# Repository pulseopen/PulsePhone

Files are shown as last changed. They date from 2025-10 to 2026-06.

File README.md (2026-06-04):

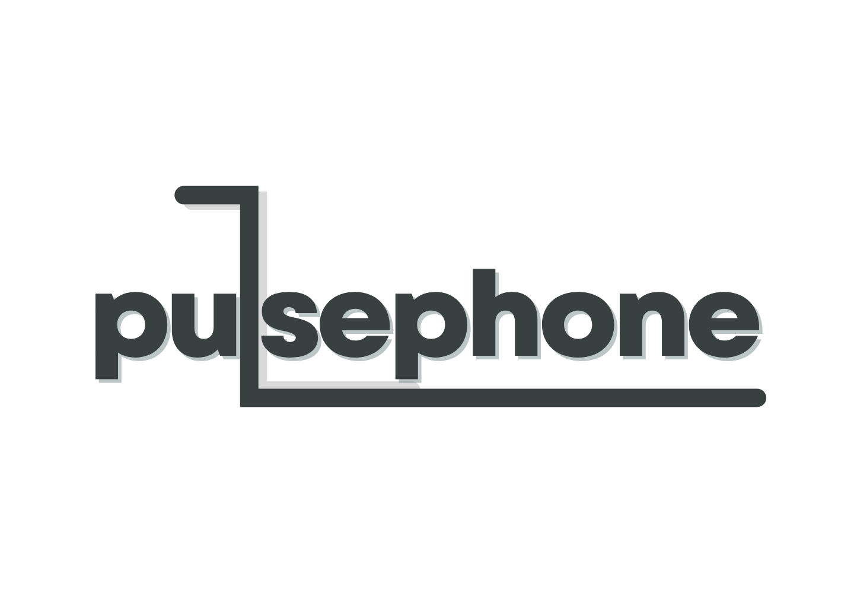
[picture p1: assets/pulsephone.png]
Pulsephonelogo


# PulsePhone — Pulse Modular Phone (MCM-iMX93 SoM)

> A modular, open-source smartphone built for repairability, upgradability, and hardware freedom.

Built around the **MCM-iMX93 System-on-Module**, PulsePhone uses **Hirose DF40** board-to-board connectors across all subsystems — keeping modules isolated, swappable, and independently developable.

---

## System Architecture

The **Main Board** is the hub of the system, hosting the MCM-iMX93 SoM, an onboard DAC, and all signal routing. Every peripheral connects to it via DF40 connectors.

| Module | Interface | Role |
|---|---|---|
| Main Board | DF40 (host) | MCM-iMX93 SoM, DAC, signal routing |
| Display Module  | MIPI/LVDS + Touch | Adapter for wide MIPI-DSI display compatability. |
| Camera Module  | MIPI CSI-2 | Adapter for wide MIPI-CSI camera compatability. |
| Audio Module | Analog | Amp, speaker, headphone, mic |

Full connector pinout in [MBI-Lite Specification](MBI-LITE.md).

---

## Project Goals

- One connector standard (DF40) across every module
- Linux (Debian + Phosh), Android, and Ubuntu Touch compatible
- Fully open: KiCad source + mechanical files under GNU GPL-V3.0

---

## Development Notes

### Main Board
> First prototype!
> Revamping design.
> PCB Design in final polishing and bug fix stages!

### Wi-Fi / Bluetooth (Former Module)
> Deffered to embedded inclusion on main board.

### Display Module
> PCB Design DONE!
> This module acts like an adapter, so PulsePhone can have a wide range of MIPI-DSI displays to be compatible with.

### Camera Module
> Design TBD

### Audio Module
> Design Started

### Mod Extension
> Planned inclusion. This extension will include an additional DF40 on the main board for community mods to the phone, like additional features.

---

## Current Project Status

- Almost ready to boot something.
- Working on wrapping up design for main board.

---

## Documentation

- Check out the [Wiki](https://github.com/pulseopen/PulsePhone/wiki)
- [MBI-Lite Module Connector Specification](MBI-LITE.md)
- [Contributing](CONTRIBUTING.md)
- [License](LICENSE)

---

## License

Hardware released under **GNU GPL-V3.0**.

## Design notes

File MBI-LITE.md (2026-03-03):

# MBI-Lite Specification — Modular Board Interconnect

MBI-Lite is the connector standard for PulsePhone's general-purpose DF-40 modules. Two blocks: Power and a flexible Custom block. Display and Camera have their own dedicated pinouts.

> **Dev Note:** DF-40 connectors are 34-pin instead of 30-pin — better mechanical stability, and honestly, 30-pin options were just hard to find.

---

## Pin Map

### Power (Pins 1–4)

| Pin | Name | Description |
|-----|---|---|
| 1 | 3V3  | Regulated 3.3V rail |
| 2 | 5V | Boosted 5V rail |
| 3 | BAT  | Raw battery voltage (3.7–4.2V) |
| 4 | GND  | Ground reference |

Don't back-feed any rail. BAT is raw battery voltage — treat it accordingly.

---

### Custom Block (Pins 5–22)

18 pins, fully open. Assign them however your module needs — GPIO, UART, SPI, I²S, USB, ADC, PWM, whatever fits. No mandated mapping.

Constraints:
- All pins operate at **3.3V (or lower) logic**
- All pins default to **high-impedance** until configured
- Any differential pair must be routed with impedance control, Include GND pins between EVERY pair of differentials.
- Anything externally accessible needs handheld-grade ESD protection

**Documentation is required.** For every pin you use, you must provide a clear description of its assignment, the reasoning behind it, any relevant electrical characteristics (pull-ups, drive strength, impedance, etc.), and how it interacts with the rest of the module. Undocumented pin usage is not up to standard with our requirements.

---

### Reserved (Pins 23–34)

Reserved for future GPIOs, system features, or optional high-speed lanes. Leave unassigned unless stated in a future revision.

---

## Electrical Rules

A few interface-specific things to keep in mind:

- **UART** — 22–100Ω series resistors recommended
- **SPI** — document clock polarity/phase in your module's profile
- **I²S** — declare whether your module is clock master or slave
- **ADC** — specify input impedance; add overvoltage protection
- **PWM** — logic-level only, add an external driver for any real load

---

## Backwards Compatibility

Modules that use pins beyond the basics will still work on boards that only implement a subset — they just won't use those features. Each module should document which pins it uses.

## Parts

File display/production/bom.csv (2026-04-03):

Designator | Footprint | Quantity | Value | LCSC Part #
C1, C2, C3, C4, C5, C6, C7, C8, C9 | 1206 | 9 | 20uF
J1 | FPC-29-P0.5 | 1 | THD THD0515-29CL-SN
J2 | FPC_7 | 1 | FPC LOGIC
J4 | Hirose_DF40C-34DS-0.4V_2x17_P0.4mm | 1 | DF40
R1 | 1206 | 1 | 100 OHM

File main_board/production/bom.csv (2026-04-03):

Designator | Footprint | Quantity | Value | LCSC Part #
3.3V1, 5V1, CLK-N1, CLK-P1, D0-N1, D0-P1, D1-N1, D1-P1, D2-N1, D2-P1, D3-N1, D3-P1, GND1, I2C3-SCL1, I2C3-SDA1, VBAT1 | TestPoint_Pad_D1.0mm | 16 | TestPoint
AUD-L1, AUD-R1 | TestPoint_Pad_1.0x1.0mm | 2 | TestPoint
BT1 | PinHeader_1x02_P2.54mm_Horizontal | 1 | Battery
C1, C10, C11, C14, C15, C16, C17, C18, C19, C20, C21, C22, C23, C24, C25, C26, C27, C28, C29, C30, C31, C32, C35, C36, C37, C7, C8, C9 | 0805 | 28 | 22uF
C12, C13, C2, C3, C33, C34, C6 | 0603 | 7 | 10uF
C4, C5 | 0603 | 2 | 2.2uF
C43 | 0603 | 1 | 100nF
D1, D4 | D_SMA | 2 | D_Schottky
D5 | 0805 | 1 | LED
J1 | USB_C_Receptacle_HRO_TYPE-C-31-M-12 | 1 | USB_C_Receptacle_USB2.0_14P
J2 | PinHeader_1x05_P2.54mm_Horizontal | 1 | Conn_01x05
J3, J4, J5 | HIROSE_DF40C-34DS-0.4V_58_ | 3 | Conn_2Rows-35Pins_MountingPin
J7 | microSD_HC_Hirose_DM3AT-SF-PEJM5 | 1 | Micro_SD_Card_Det1
L1 | L_KOHERelec_MDA7030 | 1 | 47uh
L2 | L_Wurth_WE-LQSH-4020 | 1 | 1uH
L3 | L_Wurth_WE-LQSH-4020 | 1 | 1.5uH
MCM93_MOD1 | LGA-140-080-30x30-iMX93 | 1 | MCM93_MOD
ON/OFF1 | SSSS810701 | 1 | SW_Push
R1 | 0603 | 1 | 1Mega Ohm
R10 | 0805 | 1 | 1 MΩ
R11 | 0805 | 1 | 51 kΩ
R2, R3 | 0805 | 2 | 5.1 kΩ
R4 | 0805 | 1 | 1.2 kΩ
R5, R6 | 0805 | 2 | 10 kΩ
R7 | 0805 | 1 | 1.1 MΩ
R8 | 0805 | 1 | 1kΩ
R9 | 0805 | 1 | 174 kΩ
RESET1 | SW_Push_1P1T-SH_NO_CK_KMR2xxG | 1 | SW_Push
U1 | SOIC-8_3.9x4.9mm_P1.27mm | 1 | XL1509-3.3
U2 | SOP65P640X120-20N | 1 | PCM5102APWR
U3 | VREG_MIC2877-AYFT-TR | 1 | ~
U4 | IC_TPS63020DSJR | 1 | TPS63020DSJR/3.7V Reg
U5 | SOIC-8-1EP_3.9x4.9mm_P1.27mm_EP2.41x3.3mm_ThermalVias | 1 | TP4056-42-ESOP8

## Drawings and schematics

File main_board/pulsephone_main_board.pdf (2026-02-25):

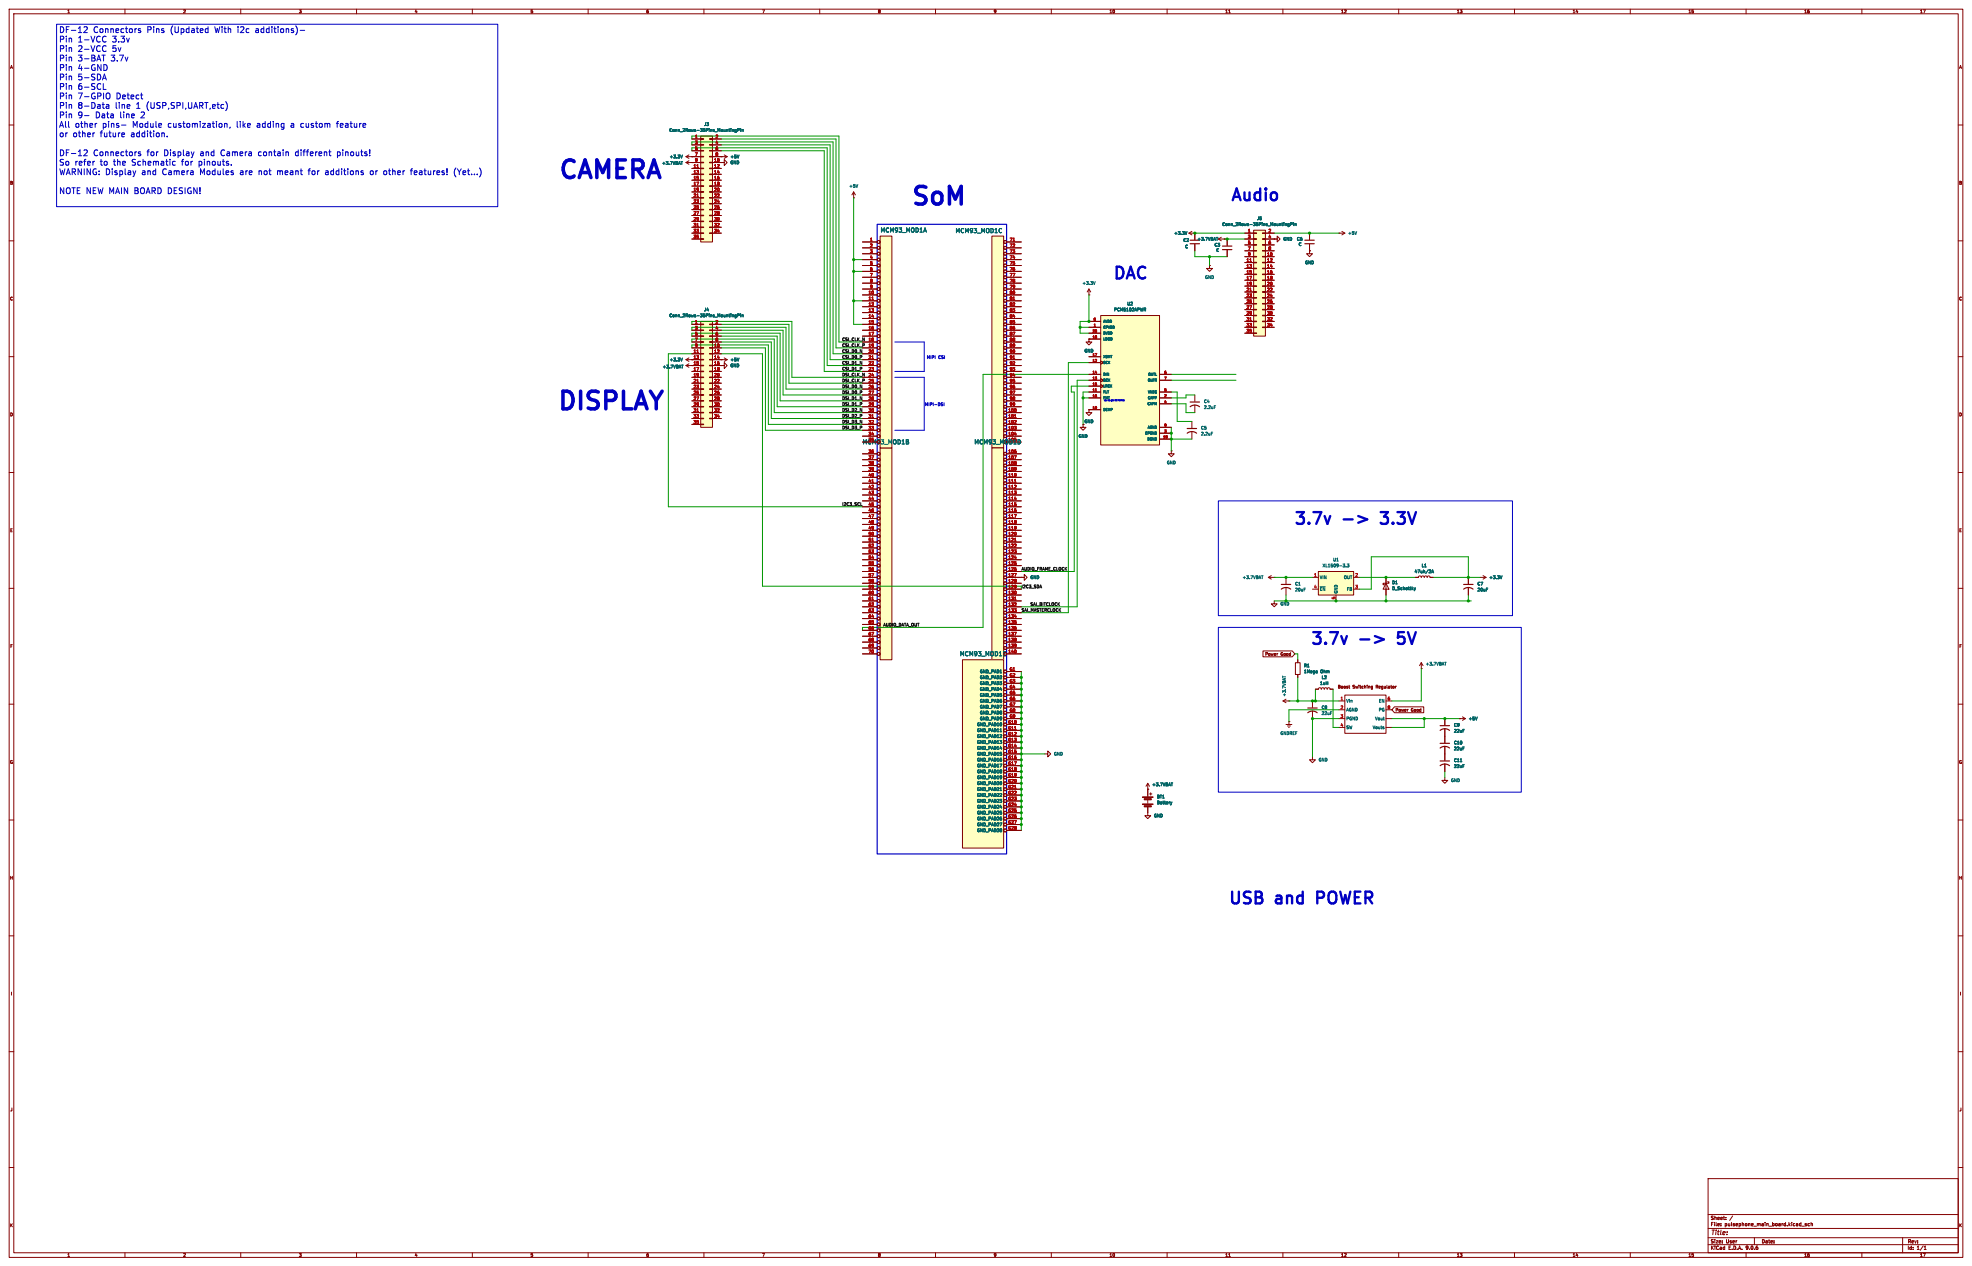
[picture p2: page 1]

Low to get I2C Format CAMERA

Power Good

Id: 1/1 Title: File: pulsephone_main_board.kicad_sch Sheet: /

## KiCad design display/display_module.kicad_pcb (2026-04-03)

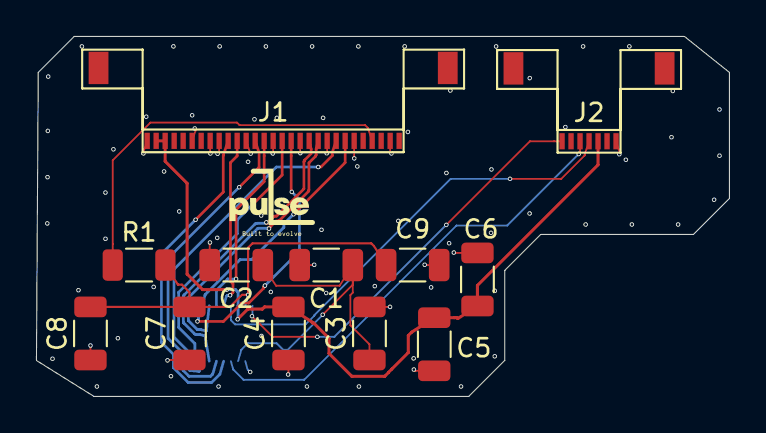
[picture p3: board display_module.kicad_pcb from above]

Board: 4 copper layers, 38.5 x 20.0 mm, 13 parts (1 on the bottom side), 18 nets.

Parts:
C1, C2, C3, C4, C5, C6, C7, C8, C9: 20uF; C_1206_3216Metric
J1: THD THD0515-29CL-SN; FPC-29-P0.5
J2: FPC LOGIC; FPC_7
J4: DF40; Hirose_DF40C-34DS-0.4V_2x17_P0.4mm
R1: 100 OHM; R_1206_3216Metric

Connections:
+3.3V: C4.2, C5.2, C6.2, J1.27, J1.28, J2.3, J4.13
+3.7VBAT: C7.2, C8.2, C9.2, J4.15, R1.2
+5V: C1.1, C2.1, C3.1, J4.14
DSI-0-N: J1.7, J4.3
DSI-0-P: J1.8, J4.4
DSI-1-N: J1.10, J4.5
DSI-1-P: J1.11, J4.6
DSI-2-N: J1.16, J4.7
DSI-2-P: J1.17, J4.8
DSI-3-N: J1.19, J4.9
DSI-3-P: J1.20, J4.10
DSI-CLK-N: J1.13, J4.1
DSI-CLK-P: J1.14, J4.2
GND: C1.2, C2.2, C3.2, C4.1, C5.1, C6.1, C7.1, C8.1, C9.1, J1.2, J1.6, J1.9, J1.12, J1.15, J1.18, J1.21, J1.22, J1.24, J1.29, J2.1, J4.16
I2C3-SCL: J2.4, J4.11
I2C3-SDA: J2.5, J4.12
unnamed: J1.4, R1.1
RST: J2.7, J4.17

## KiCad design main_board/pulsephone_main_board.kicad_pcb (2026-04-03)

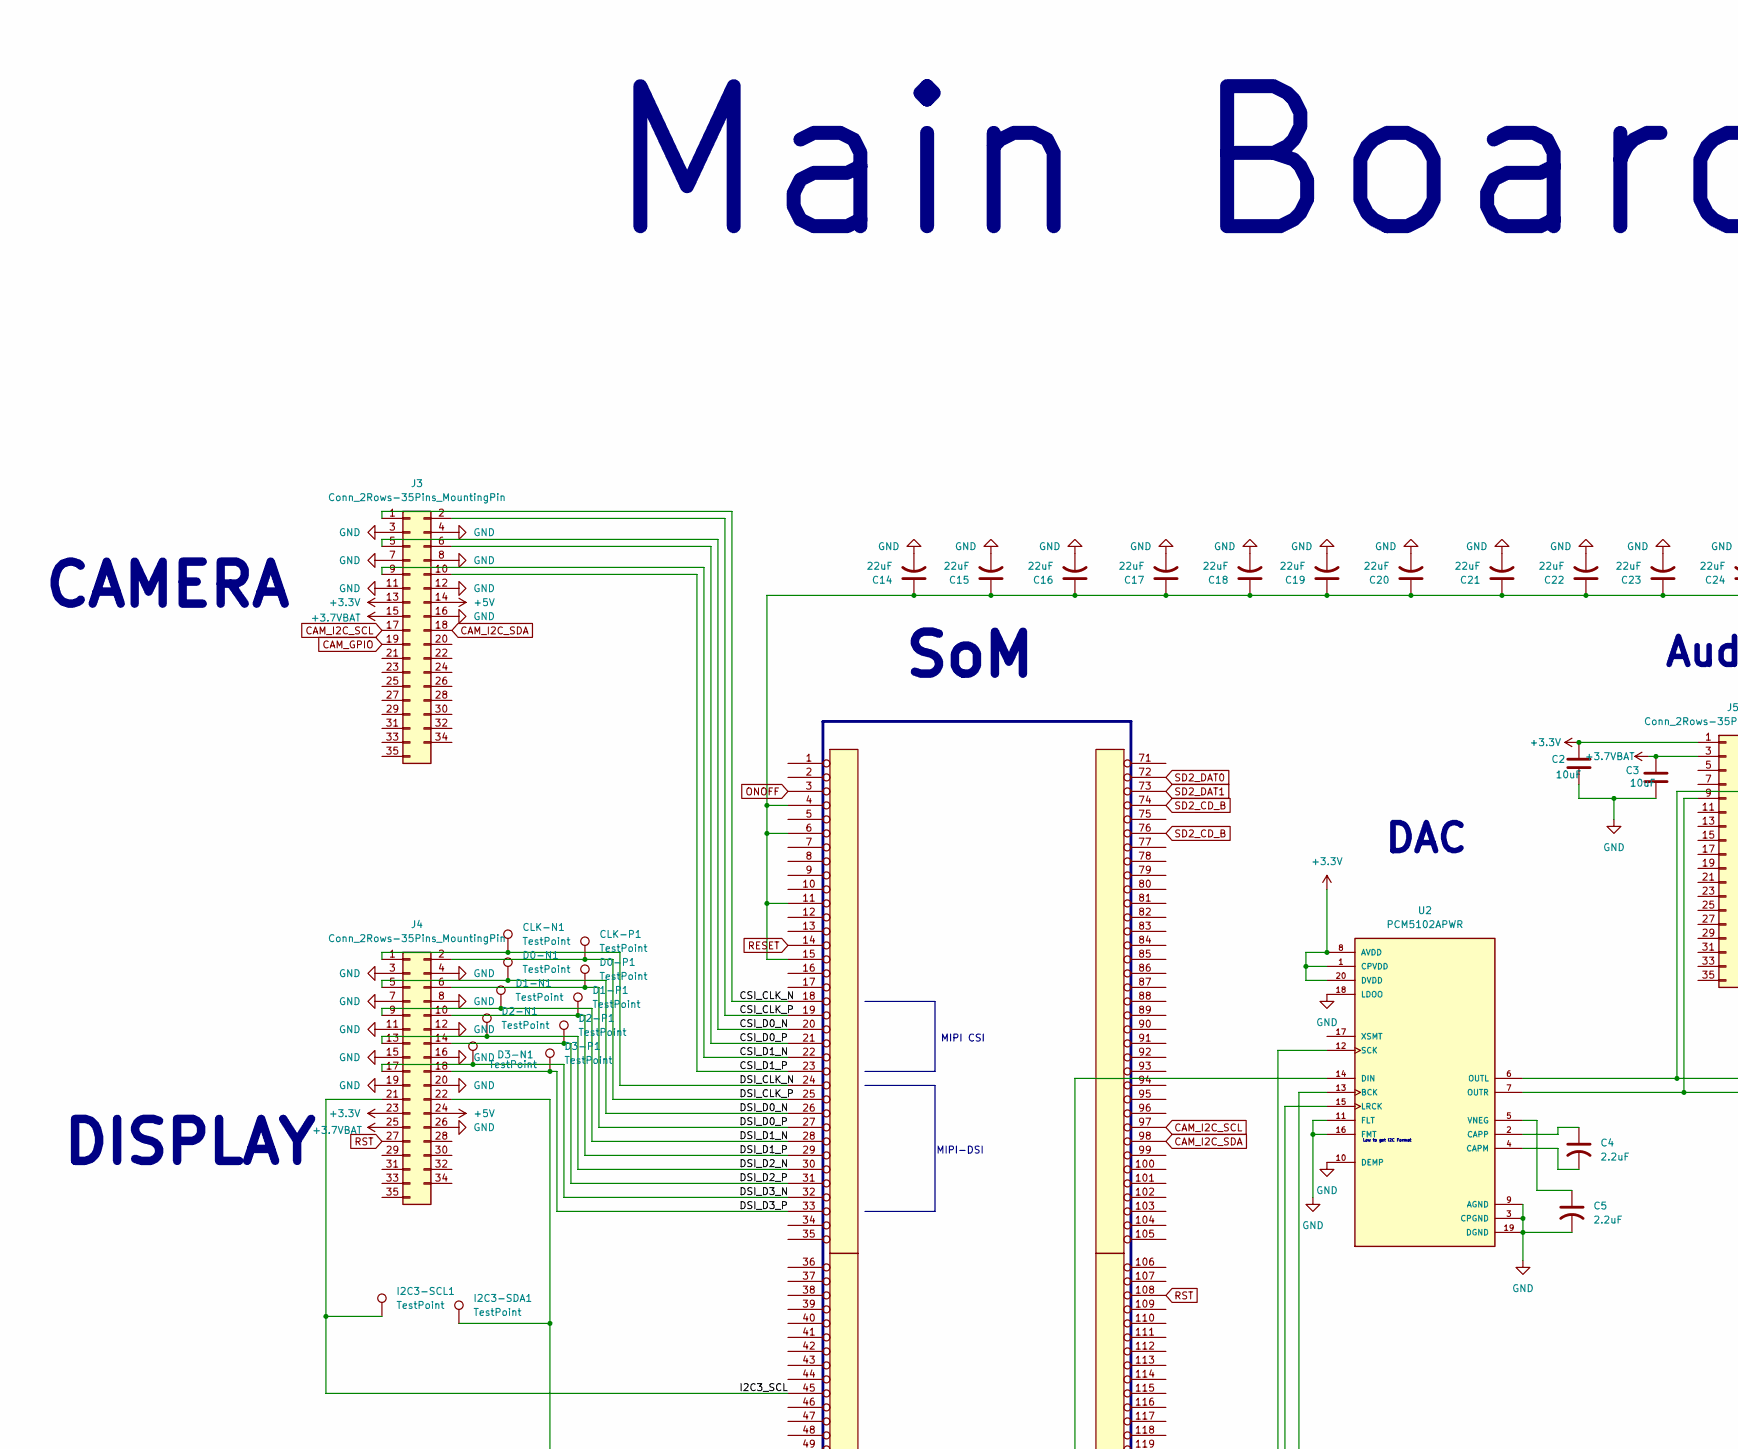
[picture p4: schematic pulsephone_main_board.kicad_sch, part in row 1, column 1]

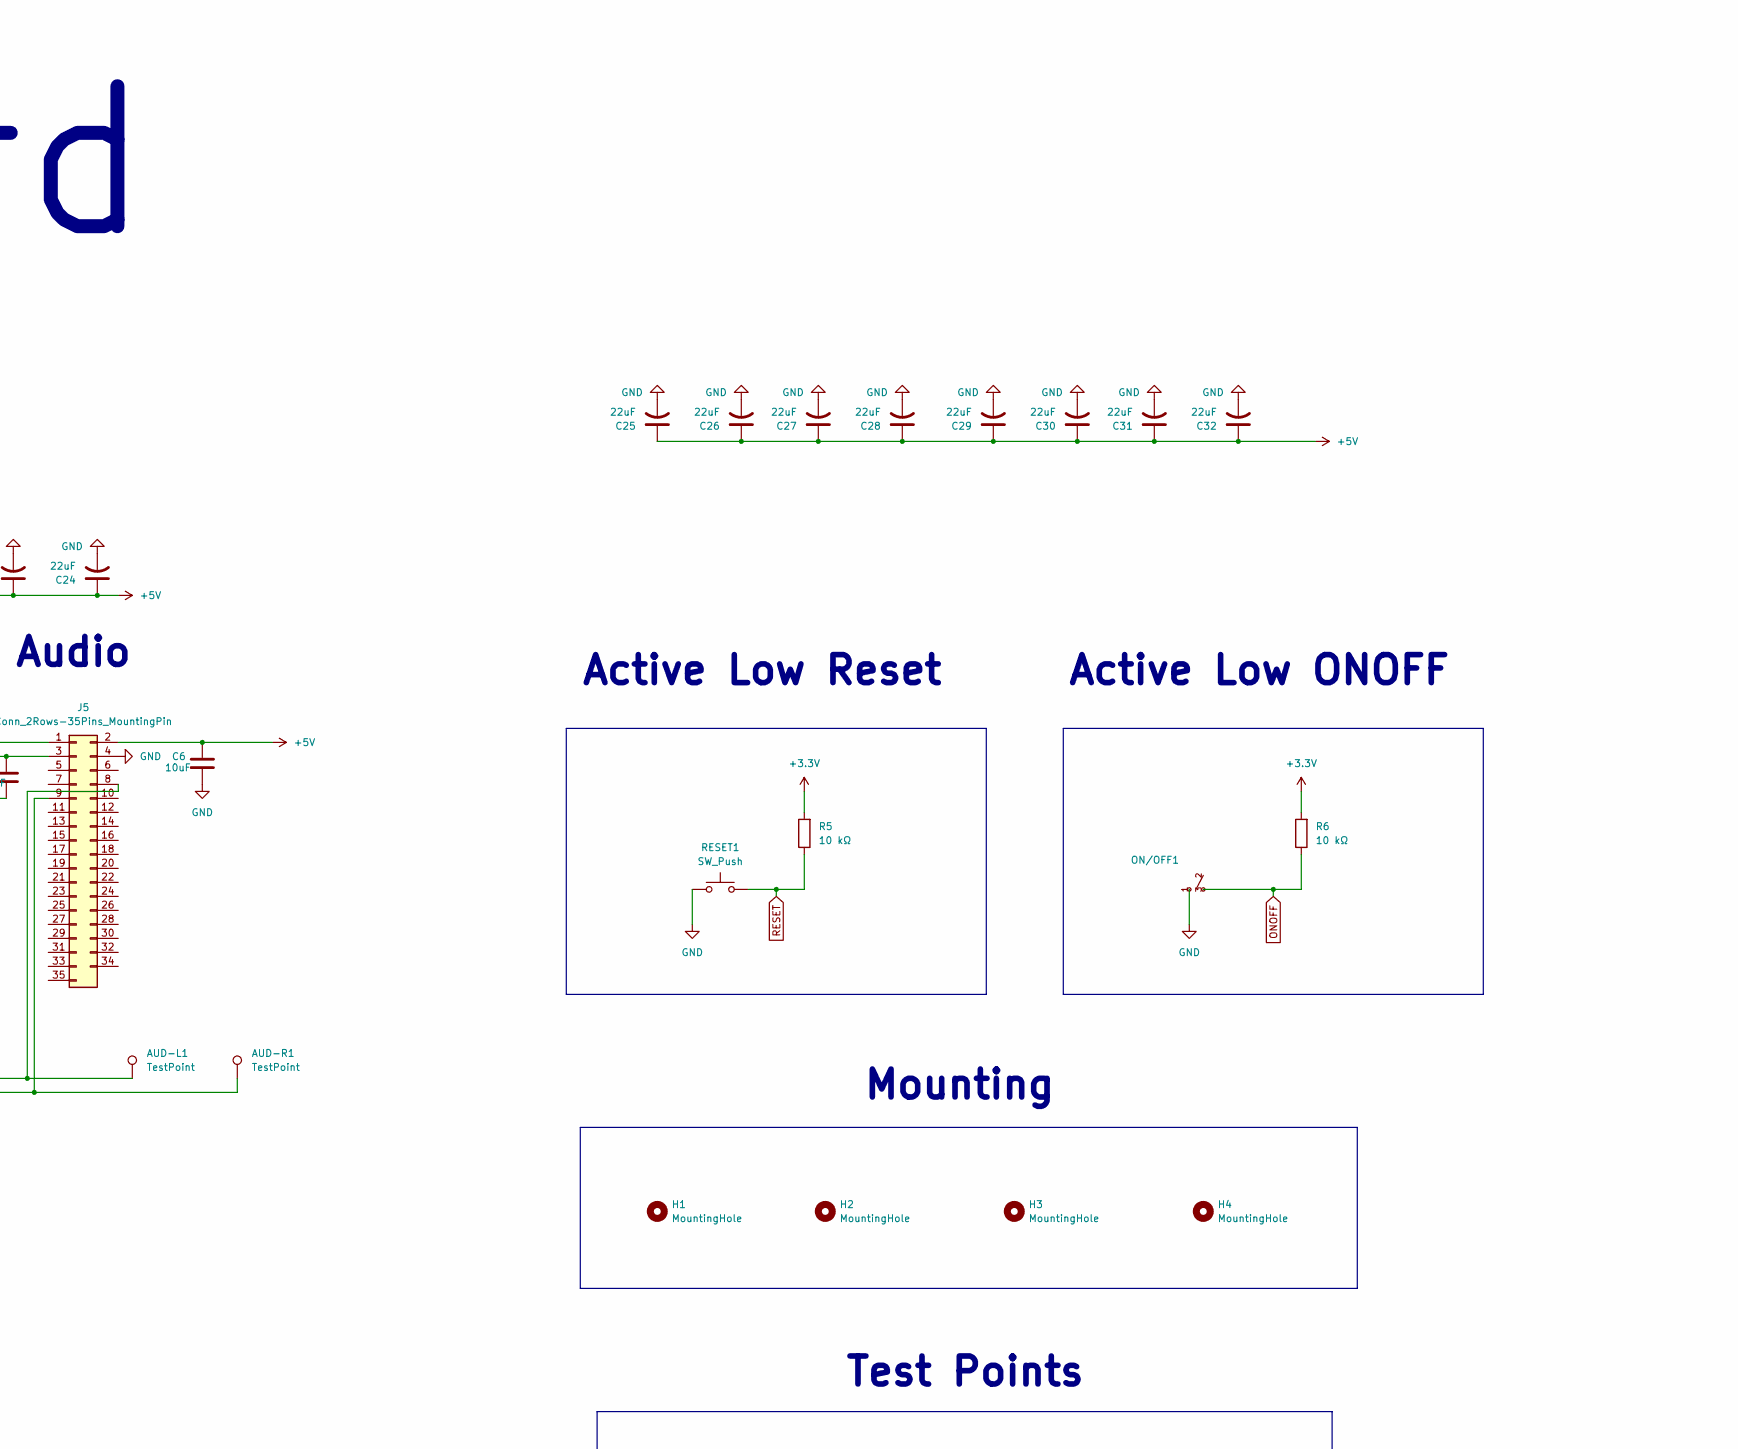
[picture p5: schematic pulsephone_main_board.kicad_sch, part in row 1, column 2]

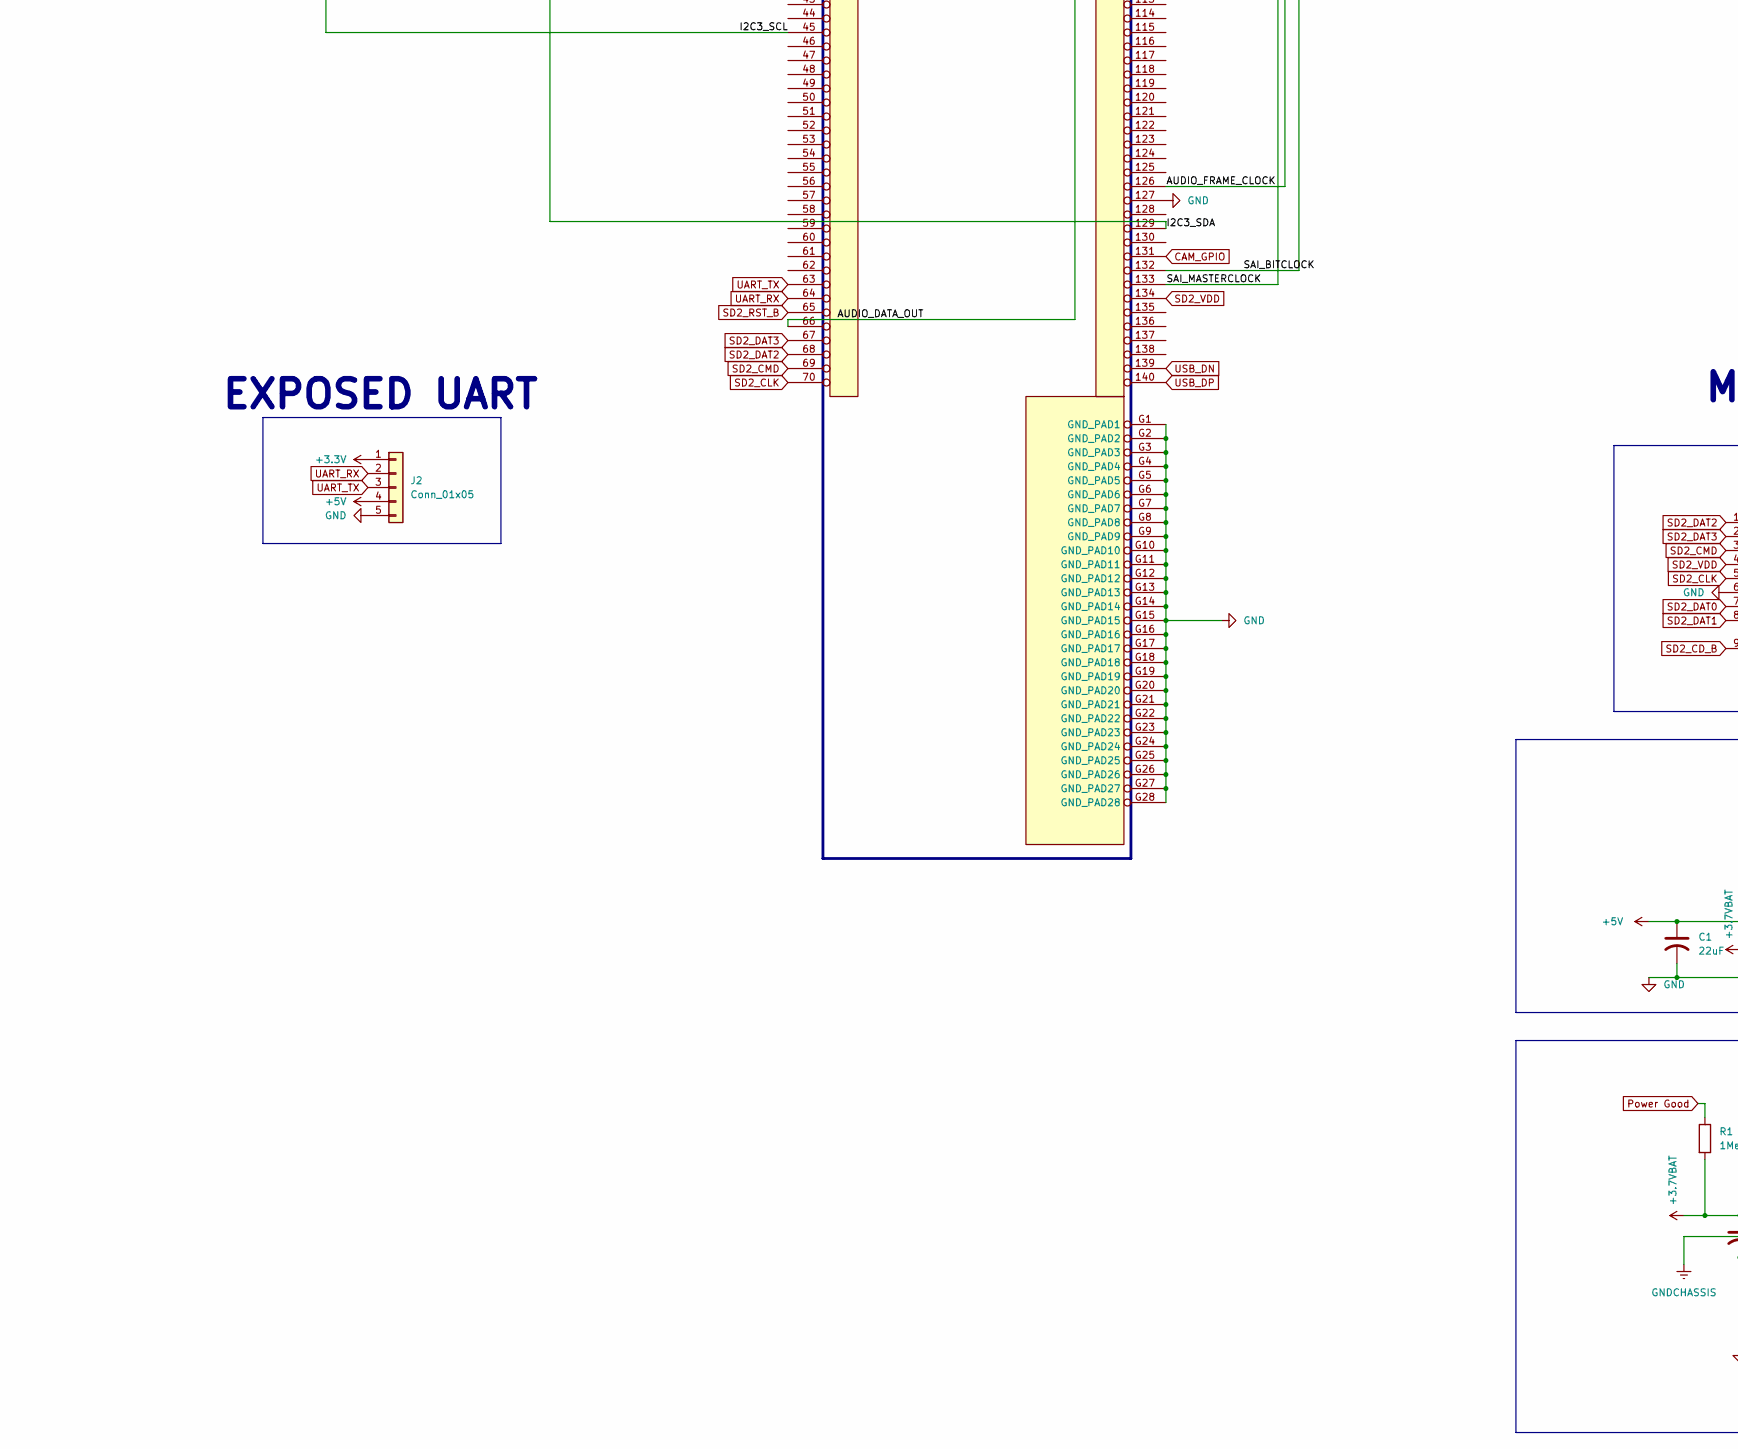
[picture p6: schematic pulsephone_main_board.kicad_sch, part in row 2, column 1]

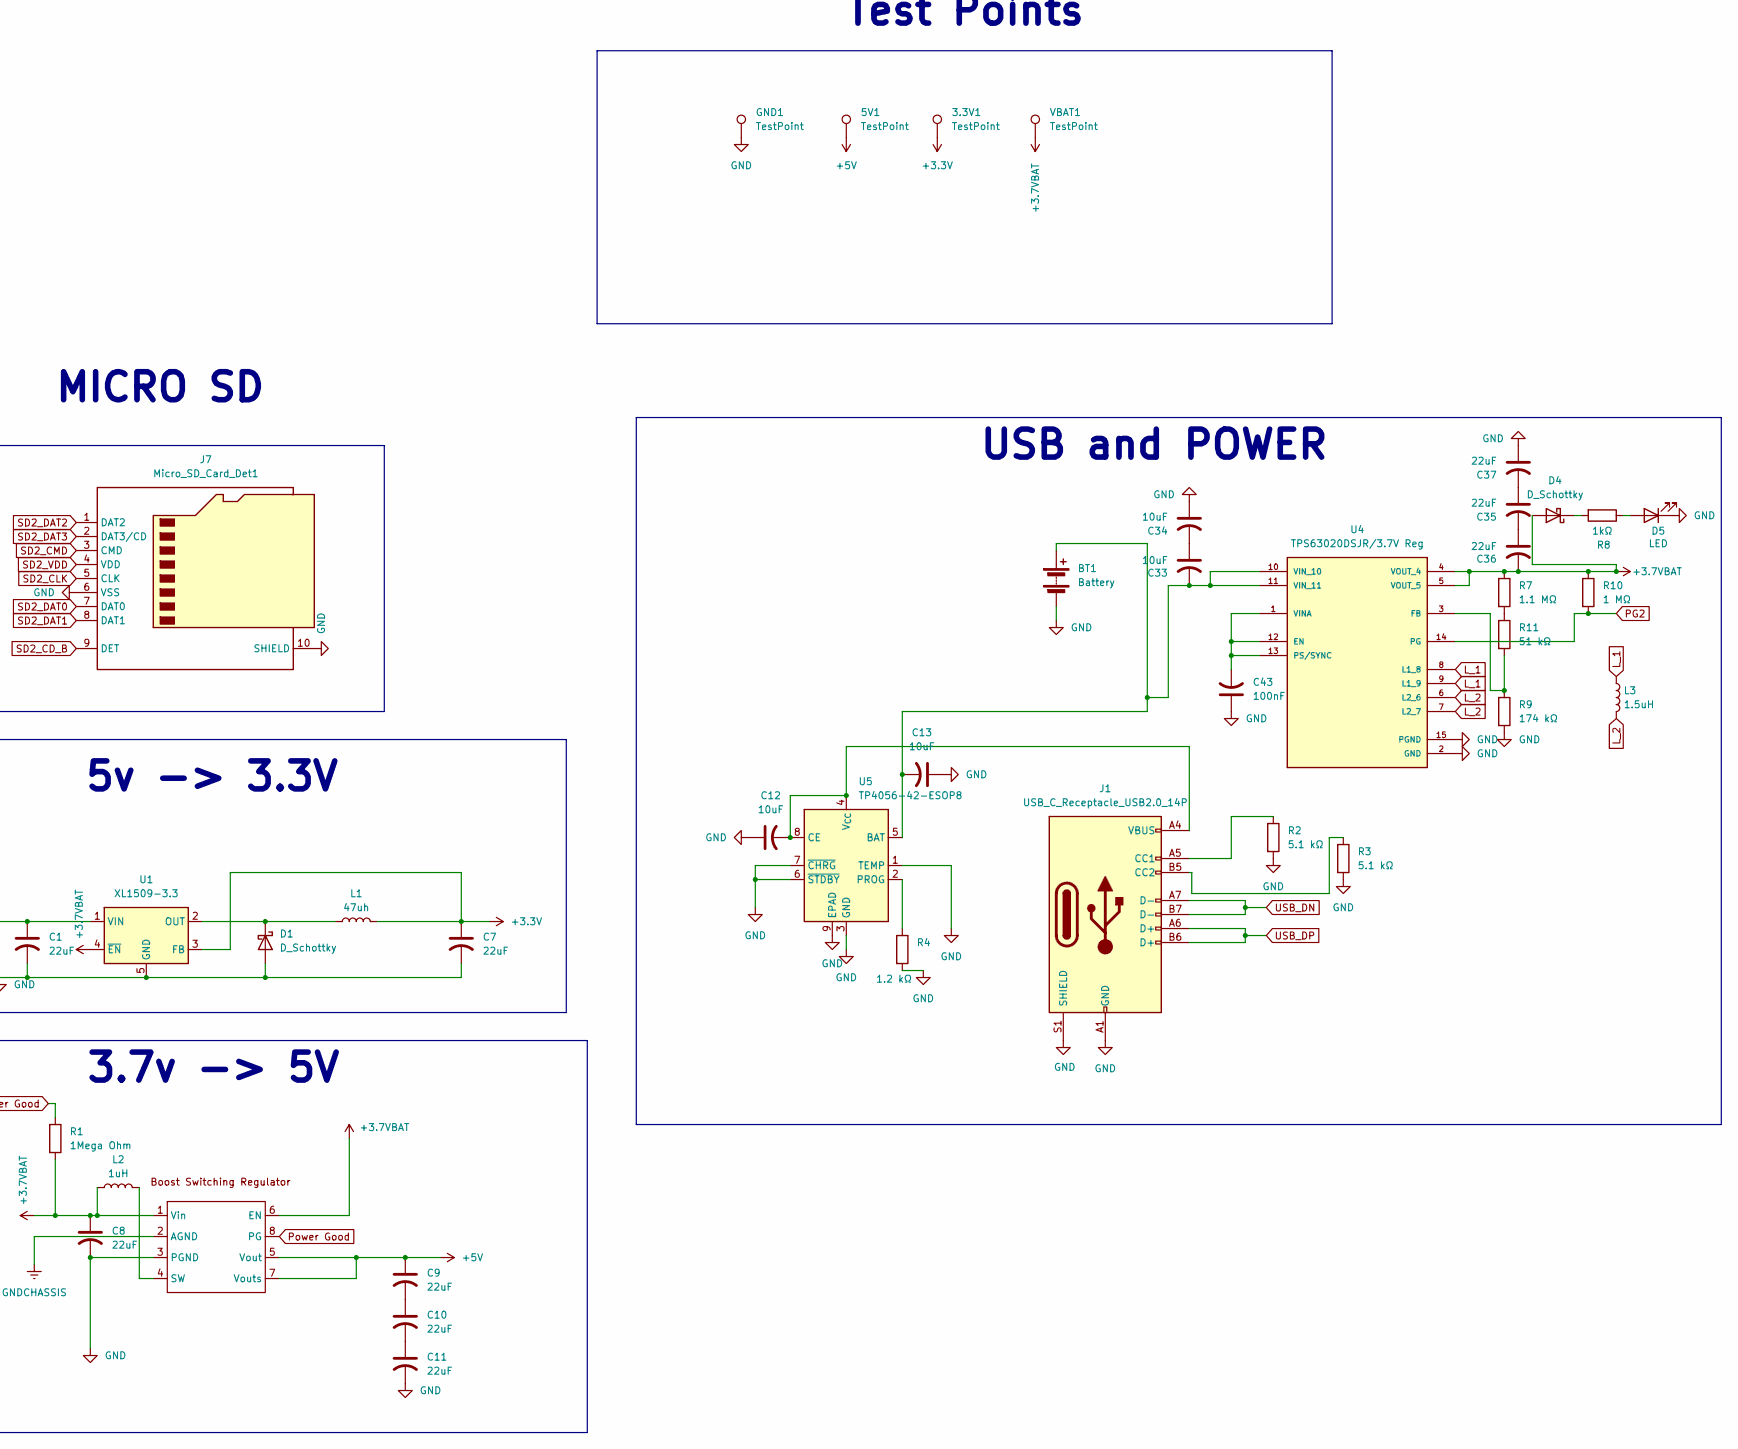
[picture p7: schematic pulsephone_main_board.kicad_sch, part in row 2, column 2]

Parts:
3.3V1, 5V1: TestPoint; TestPoint_Pad_D1.0mm
AUD-L1: TestPoint; TestPoint_Pad_1.0x1.0mm
AUD-R1: TestPoint; TestPoint_Pad_1.0x1.0mm
BT1: Battery; PinHeader_1x02_P2.54mm_Horizontal
C1, C7, C8, C9, C10, C11, C14, C15, C16, C17, C18, C19, C20, C21, C22, C23, C24, C25, C26, C27, C28, C29, C30, C31, C32, C35, C36, C37: 22uF; C_0805_2012Metric
C2, C3, C6, C12, C13, C33, C34: 10uF; C_0603_1608Metric
C4, C5: 2.2uF; C_0603_1608Metric
C43: 100nF; C_0603_1608Metric
CLK-N1: TestPoint; TestPoint_Pad_D1.0mm
CLK-P1: TestPoint; TestPoint_Pad_D1.0mm
D0-N1, D0-P1, D1-N1, D1-P1, D2-N1, D2-P1, D3-N1, D3-P1: TestPoint; TestPoint_Pad_D1.0mm
D1, D4: D_Schottky; D_SMA
D5: LED; LED_0805_2012Metric
GND1: TestPoint; TestPoint_Pad_D1.0mm
H1, H2, H3, H4: MountingHole; MountingHole_2.2mm_M2_DIN965_Pad
I2C3-SCL1, I2C3-SDA1: TestPoint; TestPoint_Pad_D1.0mm
J1: USB_C_Receptacle_USB2.0_14P; USB_C_Receptacle_HRO_TYPE-C-31-M-12
J2: Conn_01x05; PinHeader_1x05_P2.54mm_Horizontal
J3, J4, J5: Conn_2Rows-35Pins_MountingPin; HIROSE_DF40C-34DS-0.4V_58_
J7: Micro_SD_Card_Det1; microSD_HC_Hirose_DM3AT-SF-PEJM5
L1: 47uh; L_KOHERelec_MDA7030
L2: 1uH; L_Wurth_WE-LQSH-4020
L3: 1.5uH; L_Wurth_WE-LQSH-4020
MCM93_MOD1: MCM93_MOD; LGA-140-080-30x30-iMX93
ON/OFF1: SW_Push; SSSS810701
R1: 1Mega Ohm; R_0603_1608Metric_Pad0.98x0.95mm_HandSolder
R2, R3: 5.1 kΩ; R_0805_2012Metric
R4: 1.2 kΩ; R_0805_2012Metric
R5, R6: 10 kΩ; R_0805_2012Metric
R7: 1.1 MΩ; R_0805_2012Metric
R8: 1kΩ; R_0805_2012Metric
R9: 174 kΩ; R_0805_2012Metric
R10: 1 MΩ; R_0805_2012Metric
R11: 51 kΩ; R_0805_2012Metric
RESET1: SW_Push; SW_Push_1P1T-SH_NO_CK_KMR2xxG
U1: XL1509-3.3; SOIC-8_3.9x4.9mm_P1.27mm
U2: PCM5102APWR; SOP65P640X120-20N; PARTREV C
U3: VREG_MIC2877-AYFT-TR
U4: TPS63020DSJR/3.7V Reg; IC_TPS63020DSJR
U5: TP4056-42-ESOP8; SOIC-8-1EP_3.9x4.9mm_P1.27mm_EP2.41x3.3mm_ThermalVias
VBAT1: TestPoint; TestPoint_Pad_D1.0mm

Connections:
+3.3V: 3.3V1.1, C2.1, C7.1, J2.1, J3.13, J4.23, J5.1, L1.2, R5.2, R6.2, U1.3 (FB), U2.1 (CPVDD), U2.8 (AVDD), U2.20 (DVDD)
+3.7VBAT: C3.1, C8.1, C36.2, D4.2 (A), J3.15, J4.25, J5.3, L2.1, R1.2, R7.1, R10.1, U1.4 (~EN), U3.1 (Vin), U3.6 (EN), U4.4 (VOUT_4), U4.5 (VOUT_5), VBAT1.1
+5V: 5V1.1, C1.1, C6.1, C9.1, C14.1, C15.1, C16.1, C17.1, C18.1, C19.1, C20.1, C21.1, C22.1, C23.1, C24.1, C25.1, C26.1, C27.1, C28.1, C29.1, C30.1, C31.1, C32.1, J2.4, J3.14, J4.24, J5.2, MCM93_MOD1.4, MCM93_MOD1.6, MCM93_MOD1.11, MCM93_MOD1.15, U1.1 (VIN), U3.5 (Vout), U3.7 (Vouts)
/AUDIO_DATA_OUT: MCM93_MOD1.66 (31), U2.14 (DIN)
/AUDIO_FRAME_CLOCK: MCM93_MOD1.126 (21), U2.15 (LRCK)
/CSI_CLK_N: J3.1, MCM93_MOD1.18
/CSI_CLK_P: J3.2, MCM93_MOD1.19
/CSI_D0_N: J3.5, MCM93_MOD1.20
/CSI_D0_P: J3.6, MCM93_MOD1.21
/CSI_D1_N: J3.9, MCM93_MOD1.22
/CSI_D1_P: J3.10, MCM93_MOD1.23
/DSI_CLK_N: CLK-N1.1, J4.1, MCM93_MOD1.24
/DSI_CLK_P: CLK-P1.1, J4.2, MCM93_MOD1.25
/DSI_D0_N: D0-N1.1, J4.5, MCM93_MOD1.26
/DSI_D0_P: D0-P1.1, J4.6, MCM93_MOD1.27
/DSI_D1_N: D1-N1.1, J4.9, MCM93_MOD1.28
/DSI_D1_P: D1-P1.1, J4.10, MCM93_MOD1.29
/DSI_D2_N: D2-N1.1, J4.13, MCM93_MOD1.30
/DSI_D2_P: D2-P1.1, J4.14, MCM93_MOD1.31
/DSI_D3_N: D3-N1.1, J4.17, MCM93_MOD1.32
/DSI_D3_P: D3-P1.1, J4.18, MCM93_MOD1.33
/I2C3_SCL: I2C3-SCL1.1, J4.21, MCM93_MOD1.45 (10)
/I2C3_SDA: I2C3-SDA1.1, J4.22, MCM93_MOD1.129 (24)
/SAI_BITCLOCK: MCM93_MOD1.132 (27), U2.13 (BCK)
/SAI_MASTERCLOCK: MCM93_MOD1.133 (28), U2.12 (SCK)
CAM_GPIO: J3.19, MCM93_MOD1.131 (26)
CAM_I2C_SCL: J3.17, MCM93_MOD1.97 (27)
CAM_I2C_SDA: J3.18, MCM93_MOD1.98 (28)
GND: BT1.2 (-), C1.2, C2.2, C3.2, C5.2, C6.2, C7.2, C8.2, C11.2, C12.1, C13.1, C14.2, C15.2, C16.2, C17.2, C18.2, C19.2, C20.2, C21.2, C22.2, C23.2, C24.2, C25.2, C26.2, C27.2, C28.2, C29.2, C30.2, C31.2, C32.2, C34.1, C37.1, C43.1, D1.2 (A), D5.1 (K), GND1.1, J1.A1 (GND), J1.A12 (GND), J1.B1 (GND), J1.B12 (GND), J1.S1 (SHIELD), J2.5, J3.3, J3.4, J3.7, J3.8, J3.11, J3.12, J3.16, J4.3, J4.4, J4.7, J4.8, J4.11, J4.12, J4.15, J4.16, J4.19, J4.20, J4.26, J5.4, J7.6 (VSS), J7.10 (SHIELD), MCM93_MOD1.127 (22), MCM93_MOD1.G1 (GND_PAD1), MCM93_MOD1.G2 (GND_PAD2), MCM93_MOD1.G3 (GND_PAD3), MCM93_MOD1.G4 (GND_PAD4), MCM93_MOD1.G5 (GND_PAD5), MCM93_MOD1.G6 (GND_PAD6), MCM93_MOD1.G7 (GND_PAD7), MCM93_MOD1.G8 (GND_PAD8), MCM93_MOD1.G9 (GND_PAD9), MCM93_MOD1.G10 (GND_PAD10), MCM93_MOD1.G11 (GND_PAD11), MCM93_MOD1.G12 (GND_PAD12), MCM93_MOD1.G13 (GND_PAD13), MCM93_MOD1.G14 (GND_PAD14), MCM93_MOD1.G15 (GND_PAD15), MCM93_MOD1.G16 (GND_PAD16), MCM93_MOD1.G17 (GND_PAD17), MCM93_MOD1.G18 (GND_PAD18), MCM93_MOD1.G19 (GND_PAD19), MCM93_MOD1.G20 (GND_PAD20), MCM93_MOD1.G21 (GND_PAD21), MCM93_MOD1.G22 (GND_PAD22), MCM93_MOD1.G23 (GND_PAD23), MCM93_MOD1.G24 (GND_PAD24), MCM93_MOD1.G25 (GND_PAD25), MCM93_MOD1.G26 (GND_PAD26), MCM93_MOD1.G27 (GND_PAD27), MCM93_MOD1.G28 (GND_PAD28), ON/OFF1.1, R2.2, R3.2, R4.2, R9.2, RESET1.1, U1.5 (GND), U1.6 (GND), U1.7 (GND), U1.8 (GND), U2.3 (CPGND), U2.9 (AGND), U2.10 (DEMP), U2.11 (FLT), U2.16 (FMT), U2.18 (LDOO), U2.19 (DGND), U3.3 (PGND), U4.2 (GND), U4.15 (PGND), U5.1 (TEMP), U5.3 (GND), U5.6 (~STDBY), U5.7 (~CHRG), U5.9 (EPAD)
GNDCHASSIS: U3.2 (AGND)
L_1: L3.1, U4.8 (L1_8), U4.9 (L1_9)
L_2: L3.2, U4.6 (L2_6), U4.7 (L2_7)
unnamed: BT1.1 (+), C13.2, C33.2, U4.10 (VIN_10), U4.11 (VIN_11), U5.5 (BAT)
unnamed: C9.2, C10.1
unnamed: C10.2, C11.1
unnamed: C33.1, C34.2
unnamed: C35.1, C37.2
unnamed: C35.2, C36.1
unnamed: D1.1 (K), L1.1, U1.2 (OUT)
unnamed: D4.1 (K), R8.2
unnamed: D5.2 (A), R8.1
unnamed: J1.A5 (CC1), R2.1
unnamed: J1.B5 (CC2), R3.1
unnamed: AUD-L1.1, J5.8, U2.6 (OUTL)
unnamed: AUD-R1.1, J5.9, U2.7 (OUTR)
unnamed: R7.2, R11.1
unnamed: C4.2, U2.4 (CAPM)
unnamed: C4.1, U2.2 (CAPP)
unnamed: C5.1, U2.5 (VNEG)
unnamed: L2.2, U3.4 (SW)
unnamed: C43.2, U4.1 (VINA), U4.12 (EN), U4.13 (PS/SYNC)
unnamed: R9.1, R11.2, U4.3 (FB)
unnamed: C12.2, J1.A4 (VBUS), J1.A9 (VBUS), J1.B4 (VBUS), J1.B9 (VBUS), U5.4 (V_{CC}), U5.8 (CE)
unnamed: R4.1, U5.2 (PROG)
ONOFF: MCM93_MOD1.3, ON/OFF1.3, R6.1
PG2: R10.2, U4.14 (PG)
Power Good: R1.1, U3.8 (PG)
RESET: MCM93_MOD1.14, R5.1, RESET1.2
RST: J4.27, MCM93_MOD1.108 (3)
SD2_CD_B: J7.9 (DET), MCM93_MOD1.74 (4), MCM93_MOD1.76 (6)
SD2_CLK: J7.5 (CLK), MCM93_MOD1.70 (35)
SD2_CMD: J7.3 (CMD), MCM93_MOD1.69 (34)
SD2_DAT0: J7.7 (DAT0), MCM93_MOD1.72 (2)
SD2_DAT1: J7.8 (DAT1), MCM93_MOD1.73 (3)
SD2_DAT2: J7.1 (DAT2), MCM93_MOD1.68 (33)
SD2_DAT3: J7.2 (DAT3/CD), MCM93_MOD1.67 (32)
SD2_RST_B: MCM93_MOD1.65 (30)
SD2_VDD: J7.4 (VDD), MCM93_MOD1.134 (29)
UART_RX: J2.2, MCM93_MOD1.64 (29)
UART_TX: J2.3, MCM93_MOD1.63 (28)
USB_DN: J1.A7 (D-), J1.B7 (D-), MCM93_MOD1.139 (34)
USB_DP: J1.A6 (D+), J1.B6 (D+), MCM93_MOD1.140 (35)

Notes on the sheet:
3.7v -> 5V
MIPI CSI
DAC
Main Board
SoM
MIPI-DSI
5v -> 3.3V
USB and POWER
Audio
Low to get I2C Format
Mounting
Active Low Reset
Active Low ONOFF
DISPLAY
EXPOSED UART
Test Points
MICRO SD
CAMERA

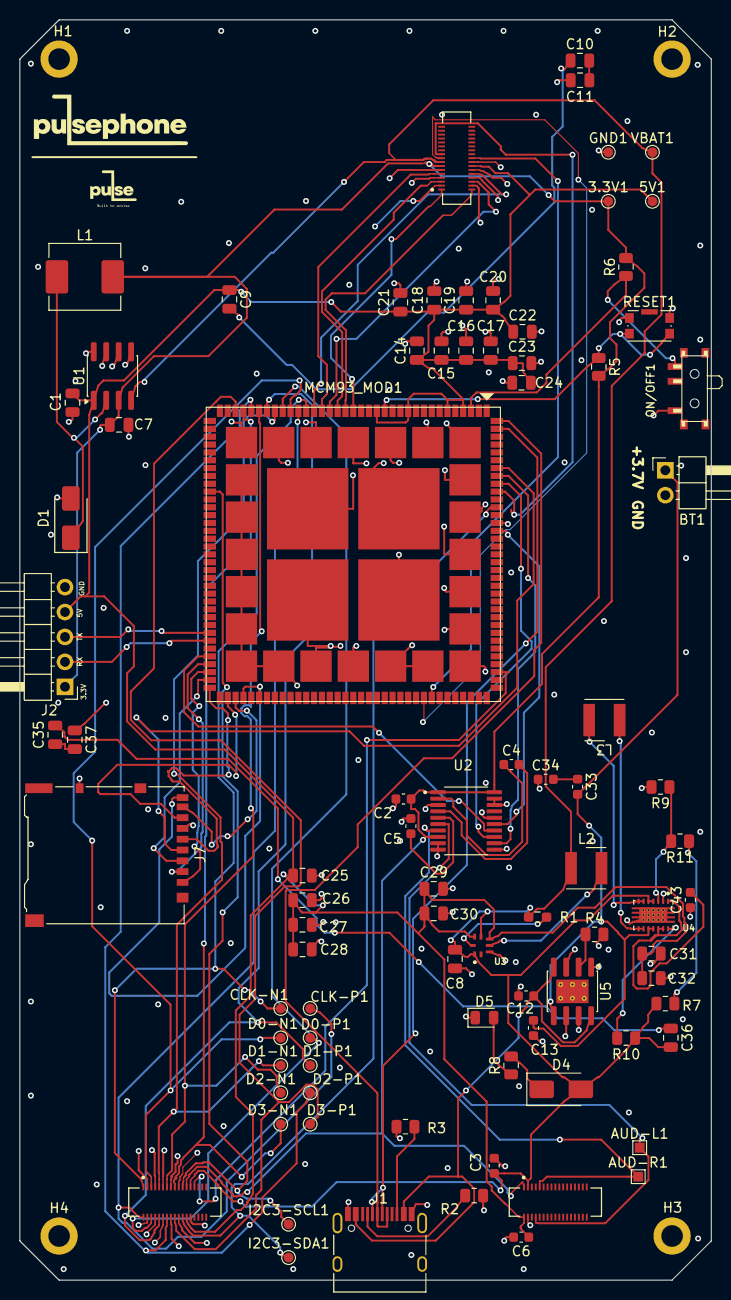
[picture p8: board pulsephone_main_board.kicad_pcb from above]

Board: 4 copper layers, 70.5 x 128.5 mm, 92 parts (0 on the bottom side), 70 nets.

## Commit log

2025-10-04 Connections for Main Board (WIP)
    [pulsephone_main_board.kicad_pcb]
2025-10-05 Battery Charger Wiring (WIP)
    [battery_usb_module.kicad_sch]
2025-10-05 PCB layout for battery/usb module
    [battery_usb_module.kicad_pcb, battery_usb_module.kicad_sch]
2025-10-06 PCB Edge cuts and layout
    [battery_usb_module.kicad_pcb]
2025-10-06 Logo edit on main pcb
    [pulsephone_main_board.kicad_pcb]
2025-10-10 Fixed vias and power planes
    Power planes on layers in1-cu and in4-cu where not added and configured, and vias where not going to correct layers.
    [bom.csv, designators.csv, positions.csv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]
2025-10-24 Routed battery module pcb
    Completed routing for the battery module section of the modular phone PCB.
    This update connects the battery modules to the main power bus and control lines,
    ensuring proper power distribution and modular interchangeability.
    [battery_usb_module.kicad_pcb]
2025-10-24 Removed uneccesary stiffiner labels on user drawings
    Stiffiner labels not necesarry since the idea of the battery module being a flex pcb got scrapped
    [battery_usb_module.kicad_pcb]
2025-10-24 Add project reminder for battery connections
    Added a reminder for changing battery connection positions.
2025-10-24 Update project reminder in README
    Adjusted battery module PCB size for case and main PCB.
2025-10-24 Fixed some wrong routing and added missed routing
    [battery_usb_module.kicad_pcb]
2025-10-24 Made MIPI-DSI connections on main board
    [pulsephone_main_board.kicad_pcb]
2025-10-24 Fixed text misplacements in front and back silkscreen
    [pulsephone_main_board.kicad_pcb]
2025-10-26 Move connector in battery module ,new usb-c footprint and symbol in pcb and schematic, fixed wrong capacitor values, and redid some wiring on battery module
    [battery_usb_module.kicad_pcb, battery_usb_module.kicad_sch, bom.csv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]
2025-10-26 Change pin headers on battery usb module to throughhole
    [battery_usb_module.kicad_pcb, battery_usb_module.stl]
2025-10-30 General Changes (Nothing Big)
    [bom.csv, positions.csv]
2025-11-06 change branding on main board
    [bom.csv, designators.csv, positions.csv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]
2025-11-09 added display folder
    [display_module.kicad_pcb, display_module.kicad_sch]
2025-11-12 replaced all power connections with copper pads and started drawing traces to them.
    [pulsephone_main_board.kicad_pcb]
2025-12-04 make new branch and start editing main board schematics
    [pulsephone_main_board.kicad_sch]
2025-12-12 Add more smoothing caps
    [pulsephone_main_board.kicad_sch]
2025-12-24 Refactor the main board design
    Mainboard is now one big pcb which is the shape and size of the phone. Modules will now attach on top of main board
    [mcm-imx93_footprint.PcbLib, pulsephone_main_board.kicad_pcb]
2026-01-08 Add in new, researched PMICs
    [pulsephone_main_board.kicad_sch]
2026-01-20 Work on completing schematics and starting pcb design
    [pulsephone_main_board.kicad_pcb, pulsephone_main_board.kicad_sch]
2026-01-21 Add charging IC and USB-C to schematic and PCB
    Next step is to review PCB layout and start drawing traces
    [pulsephone_main_board.kicad_pcb, pulsephone_main_board.kicad_sch]
2026-01-28 High speed display traces.
    [pulsephone_main_board.kicad_pcb]
2026-02-24 Finished main_board pcb, and added branding
    The next thing is to start on module development
    [pulsephone_main_board.kicad_pcb]
2026-02-24 pcb: remove backup archives and reposition board logo
    [pulsephone_main_board.kicad_pcb]
2026-02-25 pcb: update board design and related project files
    [pulsephone_main_board.kicad_pcb]
2026-02-25 pcb: update board layout and routing
    [pulsephone_main_board.kicad_pcb]
2026-02-25 Start work on display module schematic.
    Note for later: fix main board PCB, since upon inspection the board has some faults
    [display_module.kicad_sch]
2026-02-25 Start work on display module schematic.
    NOTE: rework main board PCB, since upon inspection it has multiple faults
2026-02-26 Redo PCB Routing, and added extra features
    [bom.csv, designators.csv, positions.csv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]
2026-02-26 finish display module schematic
    [display_module.kicad_sch]
2026-02-27 Finish Display module.
    The display module is basically an adapter with no fancy features, I choose to do this so pulsephone is compatible with ALL mipi displays since different manufacturers have different pinouts and stan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
    [display_module.kicad_pcb, display_module.kicad_sch]
2026-02-27 start audio module development with schematic placements
    [audio.kicad_pcb, audio.kicad_sch, battery_usb_module.kicad_pcb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]
2026-03-01 add extra ground pins to high speed MIPI LANES for reduction of signal coupling.
    [audio.kicad_sch, pulsephone_main_board.kicad_pcb, pulsephone_main_board.kicad_sch]
2026-03-01 rewire traces for new connector scheme
    [pulsephone_main_board.kicad_pcb, pulsephone_main_board.kicad_sch]
2026-03-01 fix the interrupted gnd plane by moving to 4 layers and adding gnd zones.
    [display_module.kicad_pcb]
2026-03-01 moved to a 4layer pcb with gnd zones to mitigate interrupted gnd plane.
2026-03-01 fix some errors
    [pulsephone_main_board.kicad_pcb, pulsephone_main_board.kicad_sch]
2026-03-01 remove battery switch
    [pulsephone_main_board.kicad_pcb, pulsephone_main_board.kicad_sch]
2026-03-01 add sd card slot. also add rst and onoff buttons
    [bom.csv, designators.csv, positions.csv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]
2026-03-01 concetrate center of mass ontop of display DF40c
    [display_module.kicad_pcb]
2026-03-01 more smoothing caps, and making sure board is compliant with CompuLab Standards
    [bom.csv, designators.csv, display_module.kicad_pcb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]
2026-03-02 fix PCB design errors, and fix power LED circuitry.
    [bom.csv, designators.csv, positions.csv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]
2026-03-03 git stuff
    [pulsephone_main_board.kicad_pcb, pulsephone_main_board.kicad_sch]
2026-03-09 add 3.7v regulator to VBAT for a stable vbat voltage.
    [bom.csv, designators.csv, positions.csv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]
2026-03-19 footprint size adjustments for better part compatibility when ordering
    [bom.csv, positions.csv, pulsephone_main_board.kicad_pcb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]
2026-04-03 final review change (board was ordered, prod ready verSion)
    [bom.csv, designators.csv, display_module.kicad_pcb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]
